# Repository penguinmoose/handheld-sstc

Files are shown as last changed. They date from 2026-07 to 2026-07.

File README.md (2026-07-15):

# handheld-sstc
A handheld SSTC project on PCB, designed for a large magic wand form factor, entirely powered from 8s 18650. Uses direct secondary feedback with gate driver and MOSFETs, and 555 interrupter

Actual build changes that differ from PCB:
* R13 = 100k as-built (was 150k on pcb)
* R10 = 220ohm 2W instead of 150ohm 1/4W in order to prevent it from burning out
* C6 = some sort of 0603 0.1uf SMD capacitor extracted from an old PCB because I forgot to order it on DigiKey

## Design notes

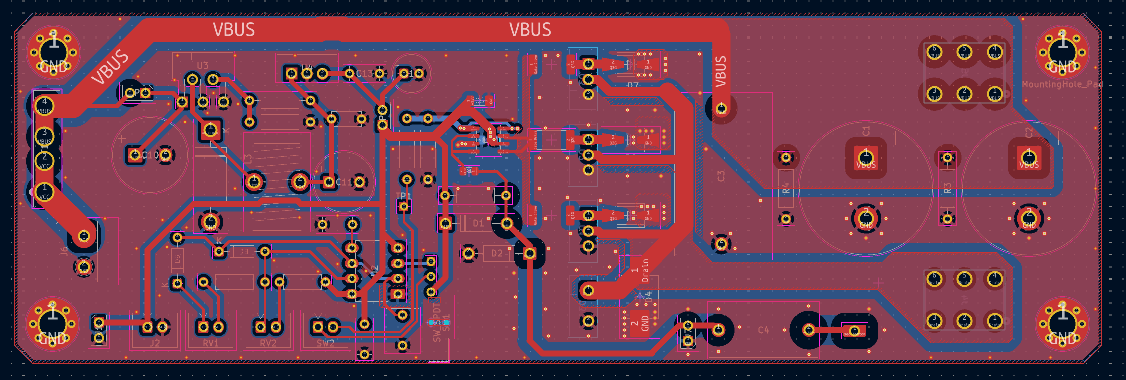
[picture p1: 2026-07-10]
screenshots/fcu-nosilkscreen.png

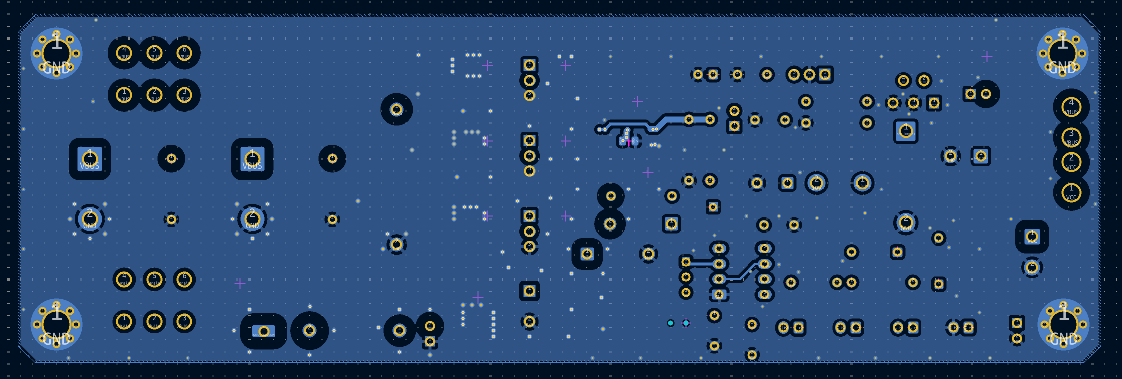
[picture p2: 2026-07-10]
screenshots/bcu-only.png

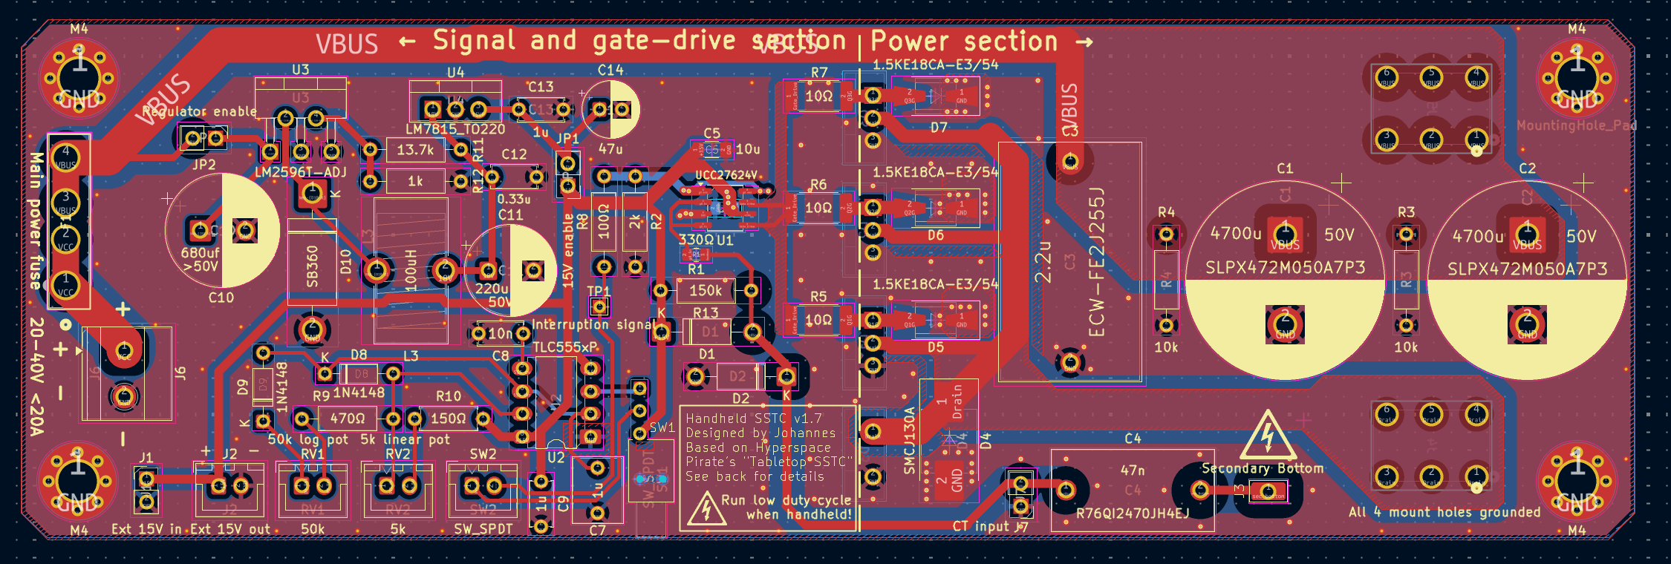
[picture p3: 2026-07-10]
screenshots/fcu-frontsilk.png

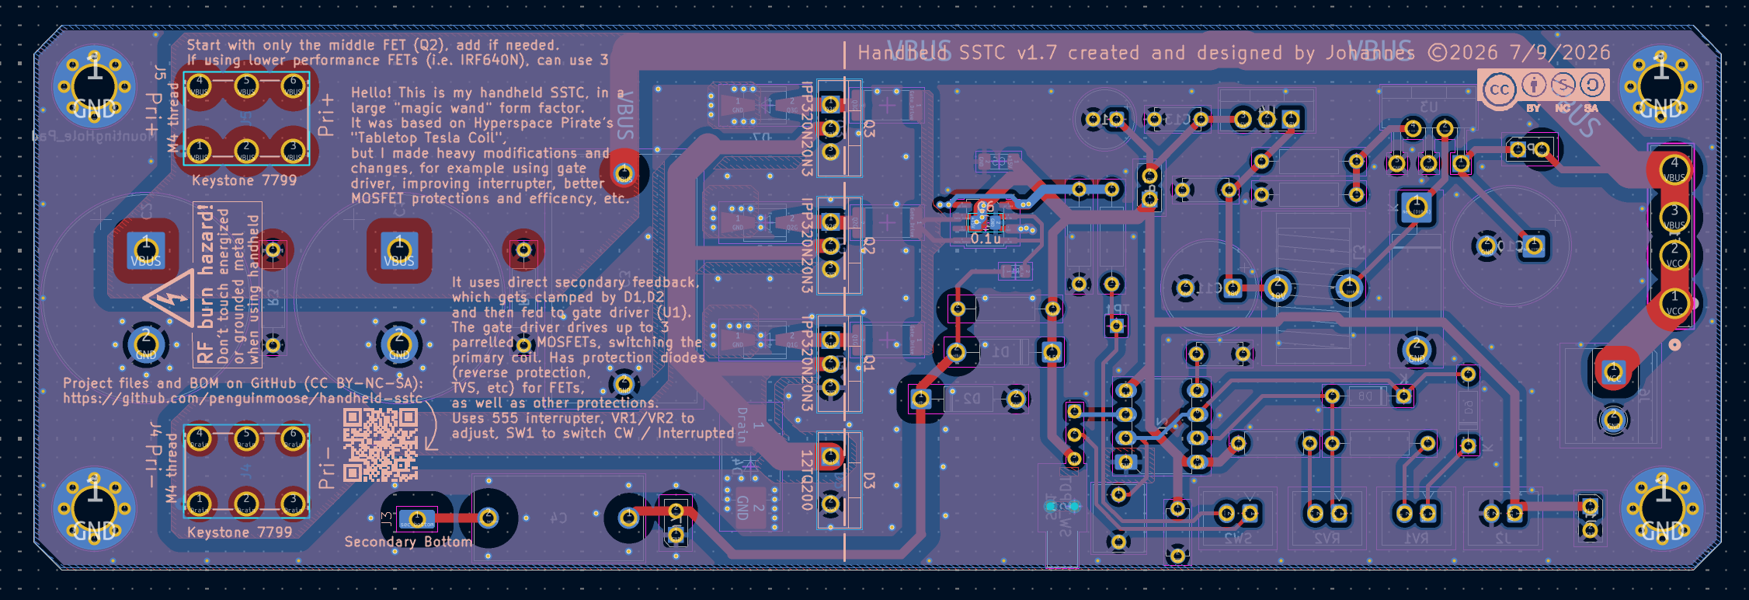
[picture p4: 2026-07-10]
screenshots/bcu-backsilk.png

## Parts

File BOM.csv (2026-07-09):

Part | Ref des | Value | Part number/description | Source | Qty | Price each | Total price | Notes
Main power capacitors | C1,C2 | 4700uF | SLPX472M050A7P3 | DigiKey | 2 | $3.81 | $7.62
Main power film capacitor | C3 | 2.2uF | ECW-FE2J225J | DigiKey | 1 | $1.88 | $1.88
Secondary drain feedback cap | C4 | 47nF | R76QI2470JH4EJ | Home | 1 | $1.01 | $1.01
Gate driver large decoupling capacitor | C5 | 10u | CGA5L1X7R1H106K160AC | DigiKey | 1 | $1.01 | $1.01 | Physically close to gate driver IC
Gate driver small decoupling capacitor | C6 | 0.1uF | C0805C104M5RACTU | Home | 1 |  |  | As close as physically possible to gate driver IC
555 timing capacitor | C7 | 1uf | R82DC4100AA60K | DigiKey | 1 | $0.60 | $0.60
555 CV pin noise filter capacitor | C8 | 10n | 50V Ceramic capacitor | Home | 1
555 decoupling capacitor | C9 | 1u | 50V Ceramic Capacitor | Home | 1
LM2596 input capacitor | C10 | 680uF | EKYC800ELL681MK30S | DigiKey | 1 | $1.86 | $1.86
LM2596 output capacitor | C11 | 220uF | 50V Electrolytic Capacitor | Home | 1
LM7815 input bypass capacitor | C12 | 0.33u | 50V Ceramic Capacitor | Home | 1
LM7815 output bypass capacitor | C13 | 1u | 50V Ceramic Capacitor | Home | 1
LM7815 output bulk capacitor | C14 | 47u | 50V Electrolytic Capacitor | Home | 1
Feedback voltage restricting diodes | D1, D2 | 200V 1A | MUR120G | DigiKey | 2 | $0.59 | $1.18
Drain-source reverse protection diode | D3 | 200V 15A | 12TQ200 | DigiKey | 1 | $2.03 | $2.03
Drain-source unidirectional TVS diode | D4 | 130VWM 209VC | SMCJ130A | DigiKey | 1 | 0.91 | $0.91
Gate reverse protection diodes | D5-D7 | 18V Bidir TVS | 1.5KE18CA-E3/54 | DigiKey | 3 | $1.41 | $4.23
555 oscillator diodes | D8, D9 | 100 V 200mA | 1N4148 | Home | 2
LM2596 diode | D10 | 60V 3A Schkty | SB360-T | DigiKey | 1 | $0.98 | $0.98
Blade fuse fuseholder | F1 | for 10A fuse | 3522-2 | DigiKey | 1 | $0.89 | $0.89 | For 10A fuse at power input
External 15V in | J1 | - | Through hole PCB double | (On PCB) | 1 |  |  | For external 15V in (instead of built in regulated 15V supply)
External 15V out | J2 | - | Through hole PCB double | (On PCB) | 1 |  |  | For external buck converter to fan
Secondary Bottom | J3 | - | Through hole PCB single | (On PCB) | 1
Primary PCB-end connection | J4, J5 | Screw terminal | Keystone 7799 | DigiKey | 2 | $0.76 | $1.52
Main power in | J6 | Screw terminal | EK508V-02P | DigiKey | 1 | $0.76 | $0.76
15V enable | JP1 | - | Dupont male header x2 | Home | 1
Regulator enable | JP2 | - | Dupont male header x2 | Home | 1
LM2596 inductor | L3 | 100uH | 100uH 3A inductor | Home | 1
MOSFETs | Q1-Q3 | Nch 200V 34A | IPP320N20N3 | DigiKey | 5 | $3.36 | $16.80 | On heatsink. Get more just in case they burn out, but really you only need one, or three if you need more current
Gate driver input resistor | R1 | 330Ω (SMD) | AC0805FR-7W330RL | DigiKey | 1 | $0.11 | $0.11 | Place physically close to gate driver
Enable pin pull down resistor | R2 | 2k | 2kΩ 0.25W through-hole | Home | 1
Input capacitor discharge resistor | R3, R4 | 10k | 10k 0.25W through-hole | Home | 1
MOSFET gate input resistor | R5-R7 | 10Ω 1%1W SMD | RMCF2512FT10R0 | DigiKey | 3 | $0.25 | $0.75
Gate driver input resistor | R8 | 100Ω | 100Ω 0.25W through-hole | Home | 1
555 off-time fixed resistor | R9 | 470Ω 1% THT | MFR-25FRF52-470R | DigiKey | 1 | $0.10 | $0.10
555 on-time fixed resistor | R10 | 150Ω 1% THT | LR0204F150R | DigiKey | 1 | $0.10 | $0.10
LM2596 feedback voltage to output | R11 | 13.7k | MFR-25FBF52-13K7 | DigiKey | 1 | $0.10 | $0.10
LM2596 feedback voltage to ground | R12 | 1k | 1kΩ 0.25W 1% THT | Home | 1
Starting resistor to gate driver | R13 | 150k | MFR-25FRF52-150K | Home | 1 |  |  | Kick-starts oscillation by pulling up gate driver input
555 off-time adjustment potentiometer | RV1 | 50k log pot | PDB181-E420K-503A2 | DigiKey | 1 | $1.77 | $1.77 | Uses JST-XH 1x02 connector on PCB
555 on-time adjustment potentiometer | RV2 | 5k linear pot | PDB181-K420K-502B | DigiKey | 1 | $1.63 | $1.63 | Uses JST-XH 1x02 connector on PCB
CW/Interrupted mode switch | SW1 | SPDT THT | CF-LD-1DC6-AW2W | DigiKey | 1 | $2.12 | $2.12
On trigger button | SW2 | 12mm SPST-NO | PV5S24019 | DigiKey | 1 | $5.59 | $5.59 | Use JST-XH 1x02 connector on PCB, it is actually a JST-XH connector, but connect the 12mm button switch.
Gate Driver | U1 |  | UCC27624VDR | DigiKey | 1 | $1.26 | $1.26
555 Timer (for interruption) | U2 |  | TLC555 | Home | 1
VCC to 18V switching buck converter | U3 |  | LM2596TVADJG | DigiKey | 1 | $2.38 | $2.38
15V linear regulator | U4 |  | LM7815CT/NOPB | DigiKey | 1 | $1.86 | $1.86
Main Power Switch | Not PCB | SPST 16A 30V | RCA1913S1ABLKBLKWHT3 | DigiKey | 1 | $3.96 | $3.96
Primary coil | Not PCB | 10awg wire |  | Home | 1
Primary wire-end connection | Not PCB | M4 | 3240027 | DigiKey | 2 | $0.89 | $1.78 | From Phoenix Contact
Secondary coil | Not PCB | 34awg wire | Red 34awg enameled wire | Amazon | 1 | $12.98 | $12.98 | Probably will only use around 1-2oz out of the 4oz
Secondary and body PVC tube | Not PCB | 2.5" ID, 24" length |  | Other
JST XH socket leads | Not PCB |  | ASXHSXH22K254 | DigiKey | 2 | $0.81 | $1.62 | There are two wires and two ends, so I can cut them in half to have 8x 5" loose end leads for connecting JST-XH
Total |  |  |  |  |  |  | $81.39

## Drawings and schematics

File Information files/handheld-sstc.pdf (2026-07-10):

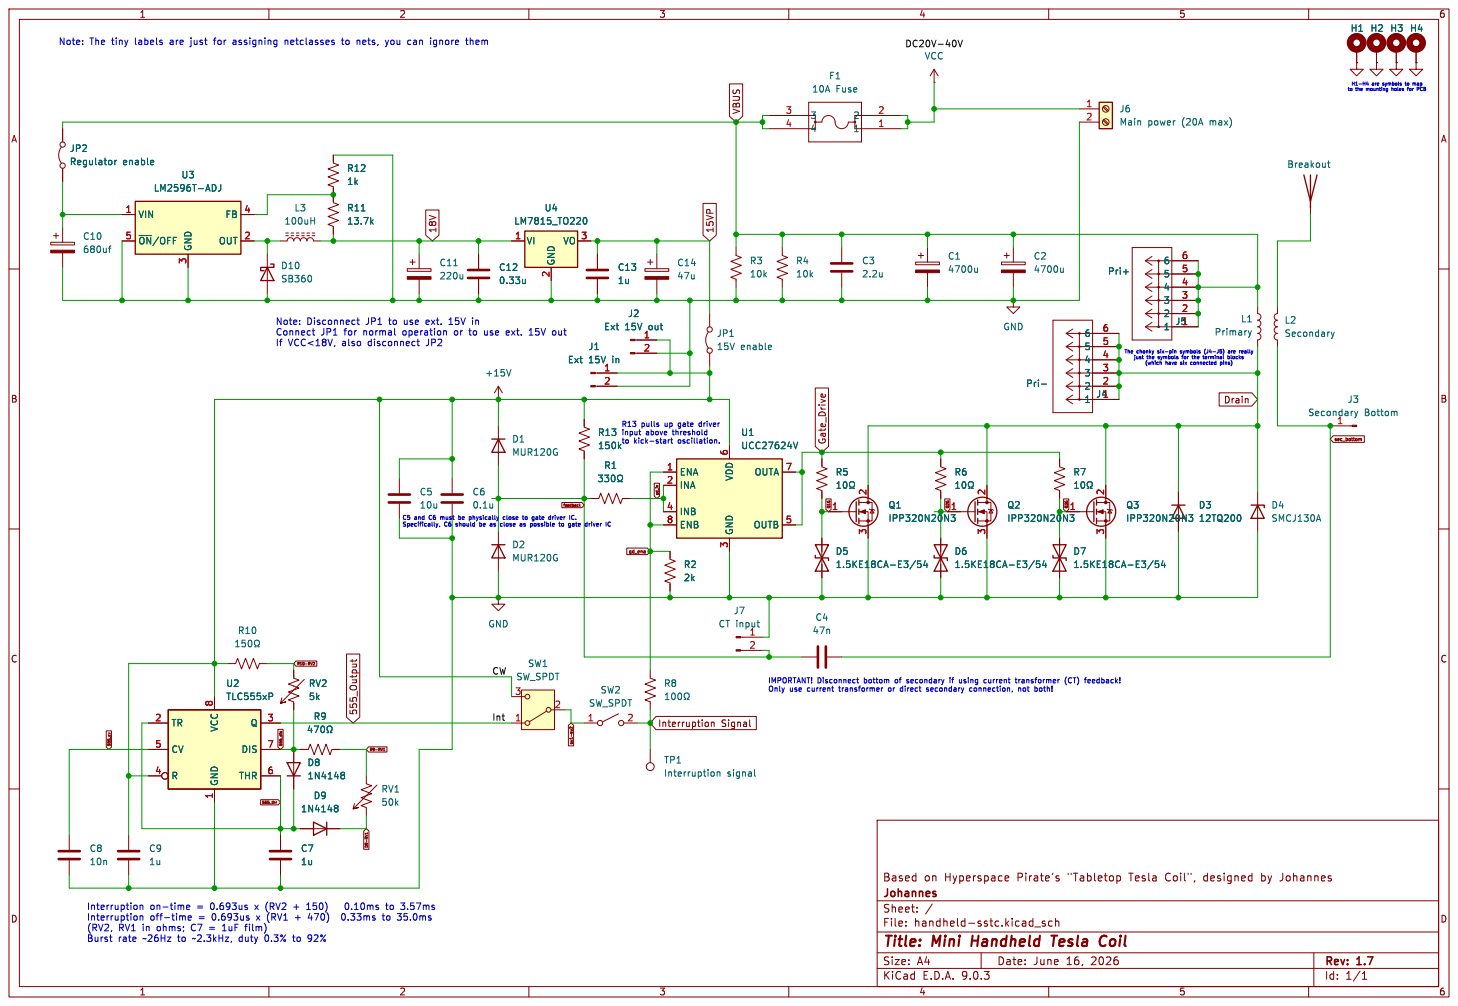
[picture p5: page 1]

R13 pulls up gate driver
input above threshold

(RV2, RV1 in ohms; C7 = 1uF film) Burst rate ~26Hz to ~2.3kHz, duty 0.3% to 92%

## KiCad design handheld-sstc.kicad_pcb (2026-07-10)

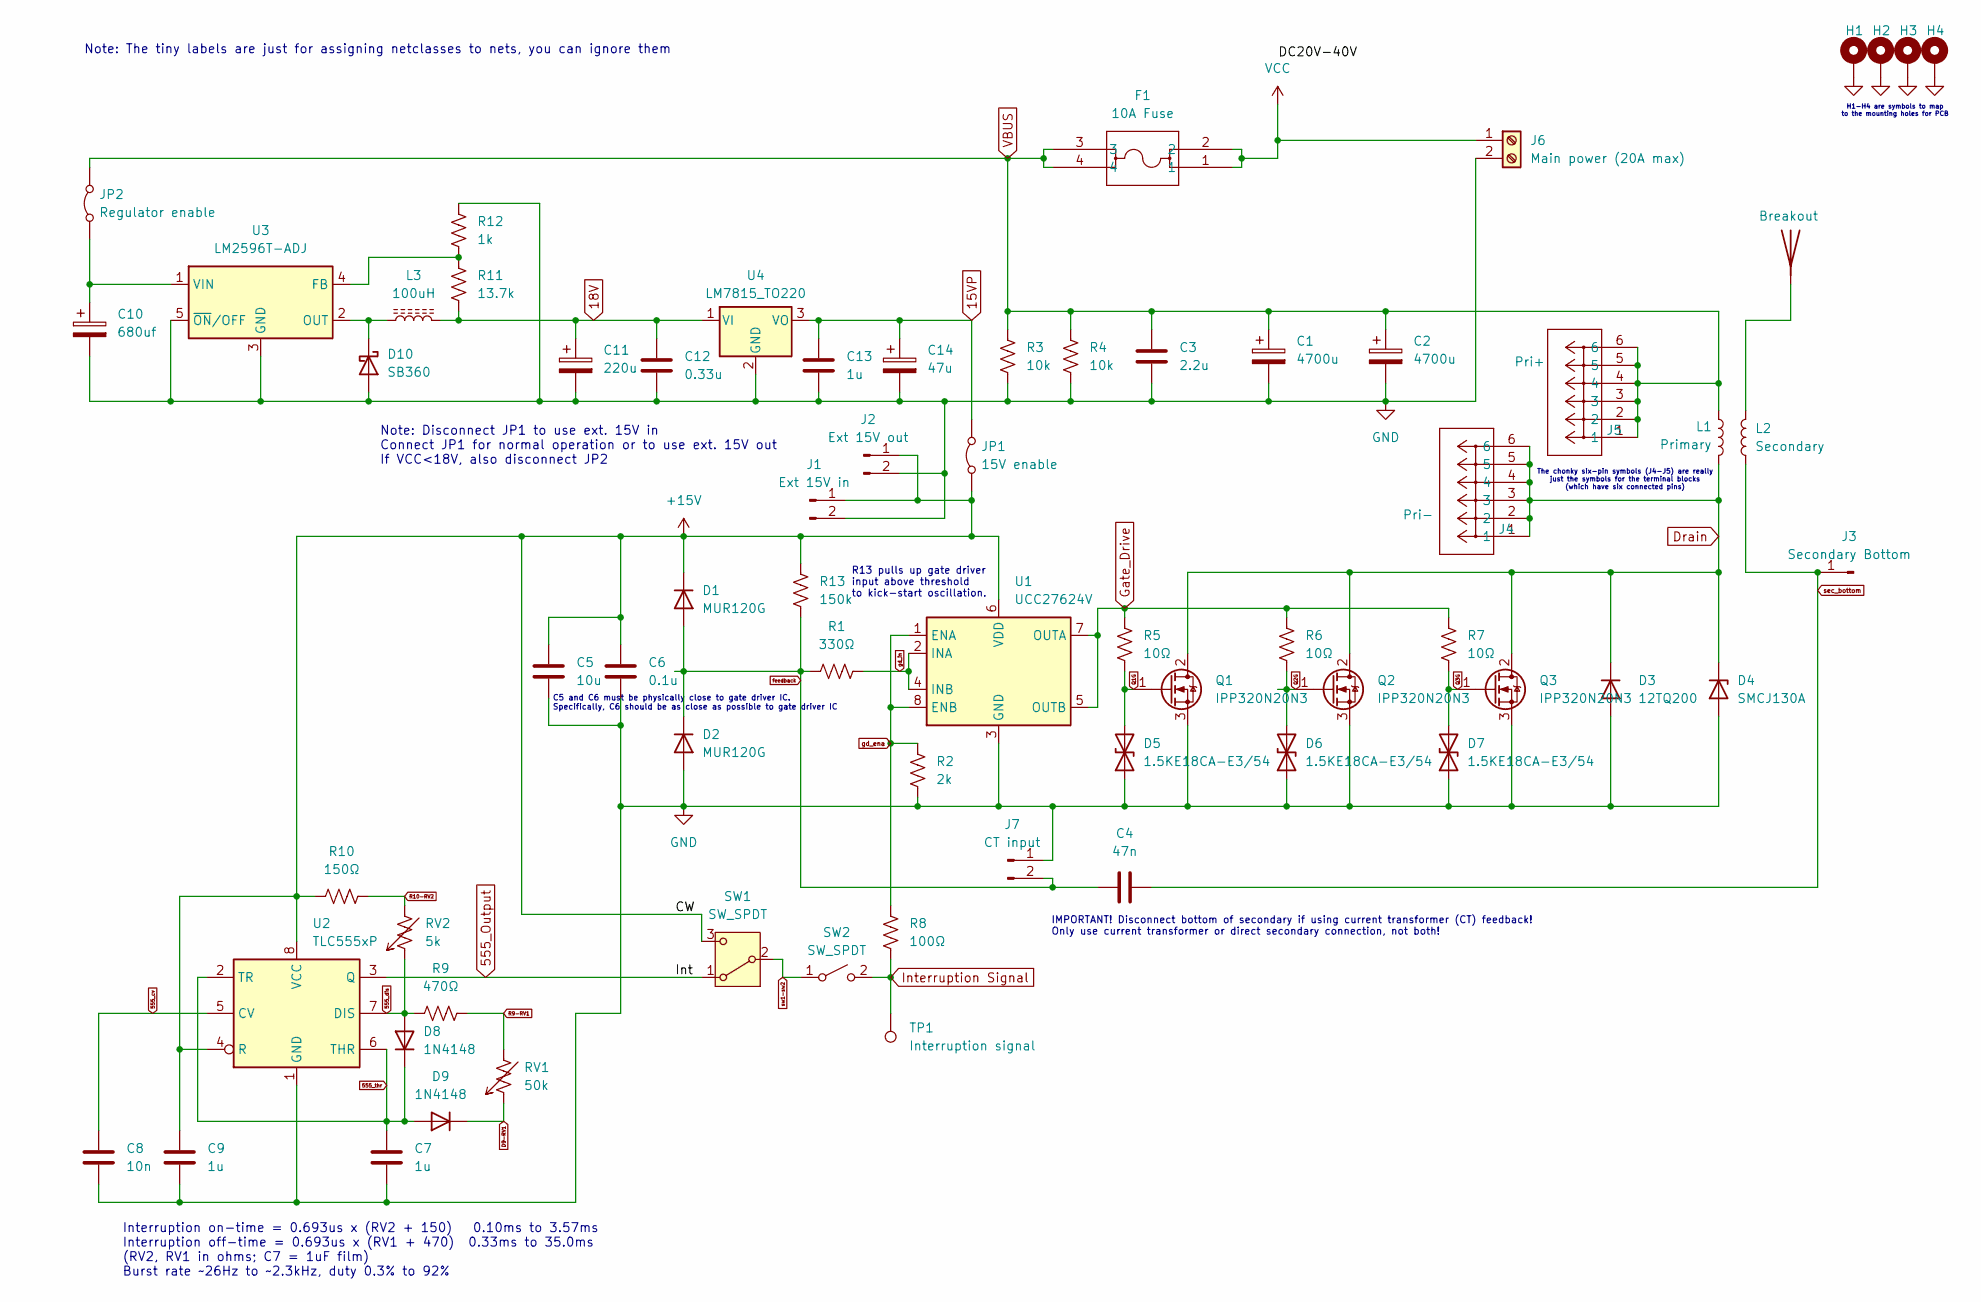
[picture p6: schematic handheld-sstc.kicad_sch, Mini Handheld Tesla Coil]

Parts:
C1, C2: 4700u; CP_Radial_D22.0mm_P10.00mm_SnapIn
C3: 2.2u; C_Rect_L26.5mm_W16mm_P22.50mm_MKS4
C4: 47n; C_Rect_L18.0mm_W9.0mm_P15.00mm_FKS3_FKP3
C5: 10u; R_1206_3216Metric_Pad1.30x1.75mm_HandSolder; Part CGA5L1X7R1H106K106AC
C6: 0.1u; C_0805_2012Metric_Pad1.18x1.45mm_HandSolder; Part C0805C104M5RACTU
C7: 1u; C_Rect_L7.2mm_W5.5mm_P5.00mm_FKS2_FKP2_MKS2_MKP2
C8: 10n; C_Disc_D5.0mm_W2.5mm_P5.00mm
C9, C13: 1u; C_Disc_D5.0mm_W2.5mm_P5.00mm
C10: 680uf; CP_Radial_D12.5mm_P5.00mm
C11: 220u; CP_Radial_D10.0mm_P5.00mm
C12: 0.33u; C_Disc_D5.0mm_W2.5mm_P5.00mm
C14: 47u; CP_Radial_D6.3mm_P2.50mm
D1, D2: MUR120G; D_DO-41_SOD81_P10.16mm_Horizontal
D3: 12TQ200; TO-220-2_Vertical
D4: SMCJ130A; D_SMC_Handsoldering
D5, D6, D7: 1.5KE18CA-E3/54; D_SMA-SMB_Universal_Handsoldering; Part SMBJ18CA
D8, D9: 1N4148; D_DO-35_SOD27_P7.62mm_Horizontal
D10: SB360; D_DO-201AD_P15.24mm_Horizontal
F1: 10A Fuse; 3522-2_KEY
H1, H2, H3, H4: MountingHole_Pad; MountingHole_4.3mm_M4_Pad_Via
J1: Ext 15V in; PinHeader_1x02_P2.54mm_Vertical
J2: Ext 15V out; JST_XH_B2B-XH-A_1x02_P2.50mm_Vertical
J3: Secondary Bottom; Conn_1x01_D1.00mm_LargeHandsolder
J4: Pri-; CONN_7799_KEY
J5: Pri+; CONN_7799_KEY
J6: Main power (20A max); TerminalBlock_Phoenix_MKDS-1,5-2-5.08_1x02_P5.08mm_Horizont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
J7: CT input; PinHeader_1x02_P2.54mm_Vertical
JP1: 15V enable; PinHeader_1x02_P2.54mm_Vertical
JP2: Regulator enable; PinHeader_1x02_P2.54mm_Vertical
L1: Primary
L2: Secondary
L3: 100uH; L_Toroid_Vertical_L16.0mm_W8.0mm_P7.62mm
Q1, Q2, Q3: IPP320N20N3; TO-220-3_Vertical
R1: 330Ω; R_0805_2012Metric_Pad1.20x1.40mm_HandSolder; Part AC0805FR-7W330RL
R2: 2k; R_Axial_DIN0207_L6.3mm_D2.5mm_P10.16mm_Horizontal
R3, R4: 10k; R_Axial_DIN0207_L6.3mm_D2.5mm_P10.16mm_Horizontal
R5, R6, R7: 10Ω; R_2512_6332Metric_Pad1.40x3.35mm_HandSolder; Part RMCF2512FT10R0
R8: 100Ω; R_Axial_DIN0207_L6.3mm_D2.5mm_P10.16mm_Horizontal
R9: 470Ω; R_Axial_DIN0207_L6.3mm_D2.5mm_P10.16mm_Horizontal
R10: 150Ω; R_Axial_DIN0207_L6.3mm_D2.5mm_P7.62mm_Horizontal
R11: 13.7k; R_Axial_DIN0207_L6.3mm_D2.5mm_P10.16mm_Horizontal
R12: 1k; R_Axial_DIN0207_L6.3mm_D2.5mm_P10.16mm_Horizontal
R13: 150k; R_Axial_DIN0207_L6.3mm_D2.5mm_P10.16mm_Horizontal
RV1: 50k; JST_XH_B2B-XH-A_1x02_P2.50mm_Vertical
RV2: 5k; JST_XH_B2B-XH-A_1x02_P2.50mm_Vertical
SW1: SW_SPDT; SW_Toggle_Copal_CF-LD-1DC6
SW2: SW_SPDT; JST_XH_B2B-XH-A_1x02_P2.50mm_Vertical
TP1: Interruption signal; TestPoint_THTPad_1.5x1.5mm_Drill0.7mm
U1: UCC27624V; SOIC-8_3.9x4.9mm_P1.27mm
U2: TLC555xP; DIP-8_W7.62mm_LongPads
U3: LM2596T-ADJ; TO-220-5_P3.4x3.7mm_StaggerOdd_Lead3.8mm_Vertical
U4: LM7815_TO220; TO-220-3_Vertical
~1: Breakout

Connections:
15VP: C13.1, C14.1, JP1.2 (B), U4.3 (VO)
18V: C11.1, C12.1, L3.2, R11.2, U4.1 (VI)
555_Output: SW1.1 (A), U2.3 (Q)
555_cv: C8.1, U2.5 (CV)
555_dis: D8.2 (A), R9.1, RV2.1, U2.7 (DIS)
555_thr: C7.1, D8.1 (K), D9.2 (A), U2.2 (TR), U2.6 (THR)
+15V: C5.1, C6.1, C9.1, D1.1 (K), J1.1, J2.1, JP1.1 (A), R10.1, R13.1, SW1.3 (C), U1.6 (VDD), U2.4 (R), U2.8 (VCC)
D9-RV1: D9.1 (K), RV1.1
Drain: D3.1 (K), D4.1 (K), J4.1, J4.2, J4.3, J4.4, J4.5, J4.6, L1.2, Q1.2 (D), Q2.2 (D), Q3.2 (D)
GND: C1.2, C2.2, C3.2, C5.2, C6.2, C7.2, C8.2, C9.2, C10.2, C11.2, C12.2, C13.2, C14.2, D2.2 (A), D3.2 (A), D4.2 (A), D5.1 (A1), D6.1 (A1), D7.1 (A1), D10.2 (A), H1.1, H2.1, H3.1, H4.1, J1.2, J2.2, J6.2, J7.1, Q1.3 (S), Q2.3 (S), Q3.3 (S), R2.2, R3.2, R4.2, R12.2, U1.3 (GND), U2.1 (GND), U3.3 (GND), U3.5 (~ON/OFF), U4.2 (GND)
Gate_Drive: R5.1, R6.1, R7.1, U1.5 (OUTB), U1.7 (OUTA)
Interruption Signal: R8.1, SW2.2 (B), TP1.1
unnamed: D10.1 (K), L3.1, U3.2 (OUT)
unnamed: C10.1, JP2.1 (A), U3.1 (VIN)
unnamed: L2.2, ~1.1
unnamed: R11.1, R12.1, U3.4 (FB)
Q1G: D5.2 (A2), Q1.1 (G), R5.2
Q2G: D6.2 (A2), Q2.1 (G), R6.2
Q3G: D7.2 (A2), Q3.1 (G), R7.2
R9-RV1: R9.2, RV1.2
R10-RV2: R10.2, RV2.2
VBUS: C1.1, C2.1, C3.1, F1.3, F1.4, J5.1, J5.2, J5.3, J5.4, J5.5, J5.6, JP2.2 (B), L1.1, R3.1, R4.1
VCC: F1.1, F1.2, J6.1
feedback: C4.1, D1.2 (A), D2.1 (K), J7.2, R1.1, R13.2
gd_ena: R2.1, R8.2, U1.1 (ENA), U1.8 (ENB)
gd_in: R1.2, U1.2 (INA), U1.4 (INB)
sec_bottom: C4.2, J3.1, L2.1
sw1-sw2: SW1.2 (B), SW2.1 (A)

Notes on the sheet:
The chonky six-pin symbols (J4-J5) are really just the symbols for the terminal blocks (which have six connected pins)
Interruption on-time = 0.693us x (RV2 + 150) 0.10ms to 3.57ms Interruption off-time = 0.693us x (RV1 + 470) 0.33ms to 35.0ms (RV2, RV1 in ohms; C7 = 1uF film) Burst rate ~26Hz to ~2.3kHz, duty 0.3% to 92%
Note: The tiny labels are just for assigning netclasses to nets, you can ignore them
R13 pulls up gate driver input above threshold to kick-start oscillation.
C5 and C6 must be physically close to gate driver IC. Specifically, C6 should be as close as possible to gate driver IC
IMPORTANT! Disconnect bottom of secondary if using current transformer (CT) feedback! Only use current transformer or direct secondary connection, not both!
Note: Disconnect JP1 to use ext. 15V in Connect JP1 for normal operation or to use ext. 15V out If VCC<18V, also disconnect JP2
H1-H4 are symbols to map to the mounting holes for PCB

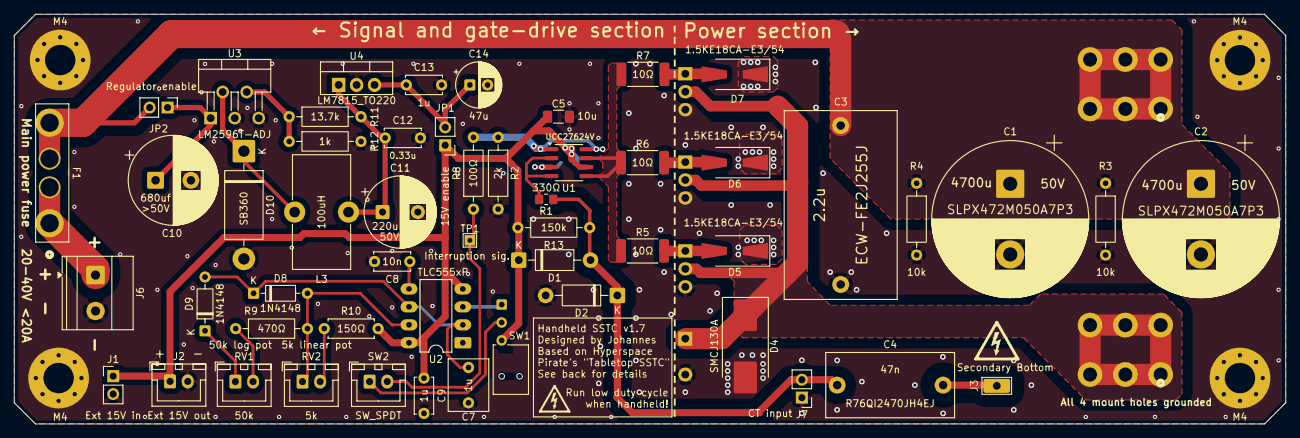
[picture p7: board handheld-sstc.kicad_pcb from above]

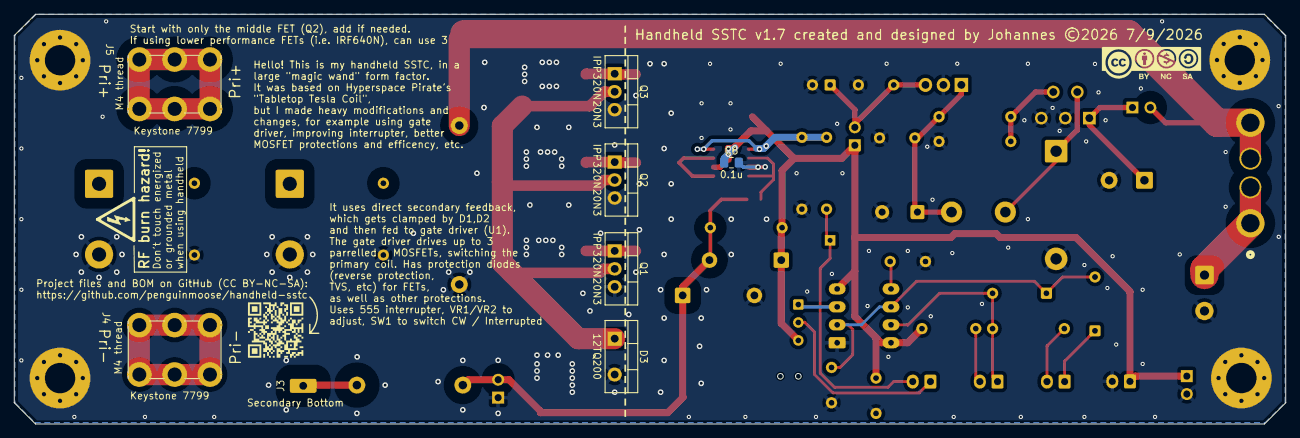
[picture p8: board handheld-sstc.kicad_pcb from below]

Board: 2 copper layers, 180.0 x 58.0 mm, 64 parts (7 on the bottom side), 27 nets.

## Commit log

2026-07-09 First commit, add project files
    [BOM.csv, DigiKey_MyList.csv, handheld-sstc.kicad_pcb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]
2026-07-10 Fix clearances and add some text
    [handheld-sstc.kicad_pcb]
2026-07-10 Fix some small problems on PCB, add screenshots and some text
    [handheld-sstc.kicad_pcb, handheld-sstc.kicad_sch]
2026-07-10 Add gerber files and minor edits
    [handheld-sstc-B_Cu.gbl, handheld-sstc-B_Mask.gbs, handheld-sstc-B_Silkscreen.gbo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]
2026-07-11 change schematic date and other really minor stuff
    [handheld-sstc.kicad_sch]
2026-07-11 Put GitHub information on Schematic
    [handheld-sstc.kicad_sch]
2026-07-15 Update README with actual build changes
    Document actual build changes that differ from PCB specifications.

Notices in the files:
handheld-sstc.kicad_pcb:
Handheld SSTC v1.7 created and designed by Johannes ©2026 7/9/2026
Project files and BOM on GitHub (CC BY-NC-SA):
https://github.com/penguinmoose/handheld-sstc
